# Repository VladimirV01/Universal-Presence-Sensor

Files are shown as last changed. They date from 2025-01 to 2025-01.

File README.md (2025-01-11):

# Universal Presence Sensor

This repository contains all the materials related to my **Universal Presence Sensor**, based on the **HLK-LD2410 radar sensor**.

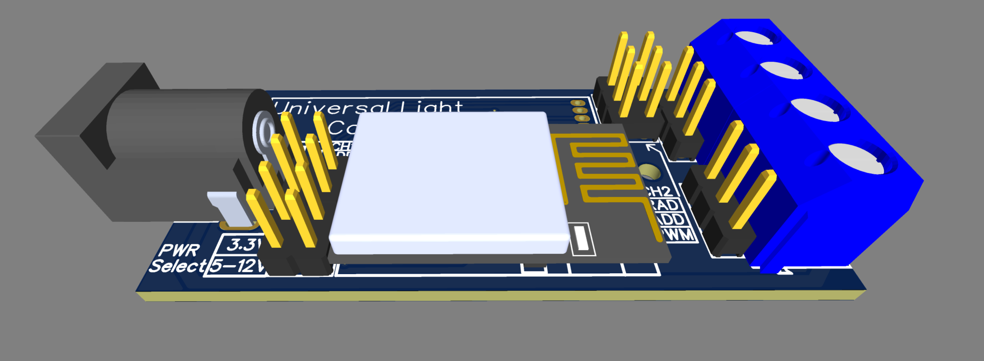
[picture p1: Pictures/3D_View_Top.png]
3D View of the Sensor
  
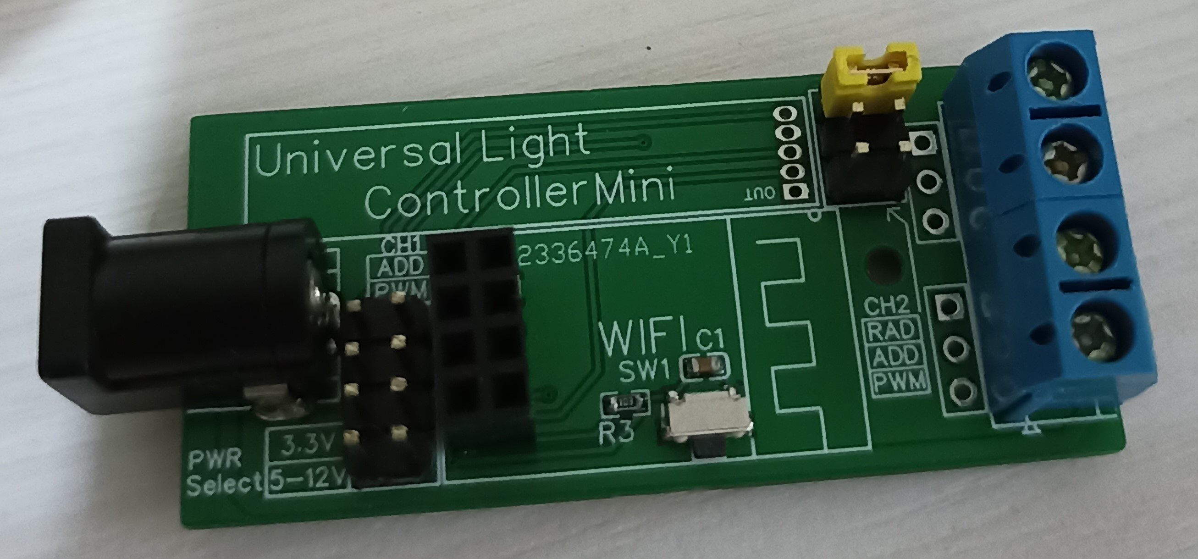
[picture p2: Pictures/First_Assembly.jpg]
Picture the Sensor
  

---

## **Features**
1. **ESP01 Module Powered by ESPHome**  
   The sensor runs ESPHome for seamless integration with Home Assistant.  

2. **Presence Detection with HLK-LD2410/HLK-LD2410B**  
   These affordable radar sensors ensure reliable presence detection.

3. **Power Supply**  
   - Standard **DC barrel jack** for power.  
   - Supports input voltage from **3.3V** up to **12V**.

4. **Configurable GPIOs**  
   The two available GPIOs can be configured to suit your specific needs.

5. **LED Strip Control**  
   - Supports brightness control for up to two 5V/12V standard LED strips via **PWM**.

6. **PIR Sensor Support**  
   Enhance presence detection with an additional **PIR motion sensor**.

---

## **Project Background**
This project began in **January 2023**, during the early days of my Home Assistant journey. At that time, presence sensors based on radar technology were expensive and hard to source in my country.  

While searching for an alternative, I discovered the **HLK-LD2410 sensors** on AliExpress at a very reasonable price. Excited by the opportunity, I purchased a few units and designed this sensor to integrate with Home Assistant using ESPHome.  

---

## **Configuration**
1. **Power**
	- Can be powered from 3.3V, in this case the "PWR Select" jumper should be set to 3.3V position
	- Can be powered from 5-12V, in which case the jumper should be changed, accordingly
	
2. **Channel 1**
	- Can control a strip of addressable LED (Set the "CH1" jumper to "ADD")
	- Can control a strip of simple LED via PWM (Set the "CH1" jumper "PWM")
	- Can be used as input (Set the "CH1" jumper to "ADD" and configure it as input)
	
3. **Channel 2**
	- Can be connected to the Radar output (Set the "CH2" jumper "RAD")
	- Can control a strip of addressable LED (Set the "CH2" jumper "ADD")
	- Can control a strip of simple LED via PWM (Set the "CH2" jumper "PWM")
	- Can be used as input (Set the "CH2" jumper to "ADD" and configure it as input)
	
### **Note:**
Please take into consideration that if you plan to control a LED strip, the input power you are giving to the module should match the power needed for the strip, as it is powered directly from the input.

Example 1: If you want to power a WS2812B strip of addressable LEDs, then you need to power the module from 5V and set the input power jumper accordingly.

Example 2: If you want to control a 12V simple Cold White LED strip, you need to power the module from 12V.

Example 3: If you want to use the module for presence detection only, paired with the radar sensor, it can be safely powered from 3.3V only.

---

## **Use Cases**
Currently, I have **three sensors** installed in my home, each serving unique purposes:

1. **Bathroom Automation**  
   - Installed to automate the lights.  
   - Operates with a success rate of **99.5%**, with no false positives and almost no false negatives.  

2. **Work Desk Setup**  
   - Equipped with one radar and one PWM output to control a LED strip that illuminates my keyboard based on specific conditions.  

3. **Closet Lighting**  
   - Similar to the bathroom sensor, it controls the lights.  
   - Performance is slightly affected by the closet’s layout, as items may obstruct the radar’s view in certain scenarios.  

---

## **Why This Project?**
At the time, affordable radar-based presence sensors were a rarity. By creating this sensor, I managed to fill a gap in the market while learning and experimenting with Home Assistant and ESPHome.  

---

## **Improvements for next version:**
- Power via Type C
- Decrease the footprint
- Revisit the case
- Make the case assembly snap in place without screws
- Add ferrite beads on the power line to the PIR sensor to try and solve the false positives

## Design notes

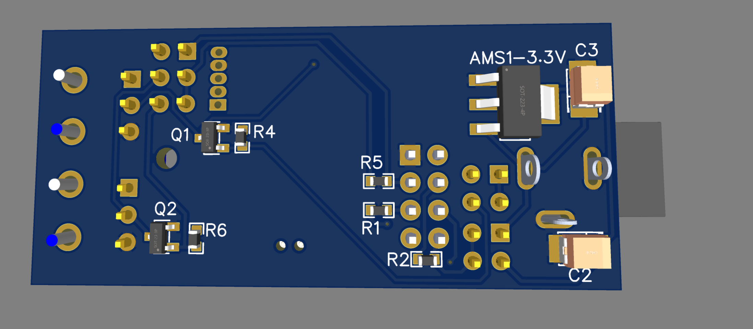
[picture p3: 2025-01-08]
Pictures/3D_View_Bottom.png

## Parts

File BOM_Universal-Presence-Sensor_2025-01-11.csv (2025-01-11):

ID | Name | Designator | Footprint | Quantity | Manufacturer Part | Comment
1 | AMS1117-3.3V | AMS1-3.3V | SOT-223-4_L6.5-W3.5-P2.30-LS7.0-BR | 1 | AMS1117-3.3V | Not needed if powered by 3.3V and the PWR jumper set accordingly.
2 | 0.1u | C1 | C0603 | 1 |  | Not mandatory but beneficial if Reset button is soldered
3 | 10uF Tantalum | C2,C3 | CAP-SMD_L3.5-W2.8 | 2 | TCQB686M006R0070E | Not needed if powered by 3.3V
4 | DC JACK | DC1 | DC-IN-TH_DC-005-20A | 1 | DC-005-20A | Input power socket
5 | LED1 | J1 | HDR-M-2.54_1X3 | 1 |  | Optional header for connecting Addressable LEDs
6 | Ch1 Select | J2 | HDR-M-2.54_2X2 | 1 |  | Jumper for selecting the CH1 fucntionality. Not mandatory, can be a solder bridge
7 | LED2 | J3 | HDR-M-2.54_1X3 | 1 |  | Optional header for connecting Addressable LEDs
8 | Bypass Reg | J5 | HDR-M-2.54_2X2 | 1 |  | Jumper to select the power option. Not mandatory, can be a solder bridge
9 | Ch2 select | J6 | HDR-M-2.54_2X3 | 1 |  | Jumper for selecting the CH2 fucntionality. Not mandatory, can be a solder bridge
10 | IRLML2502 | Q1,Q2 | SOT-23-3_L2.9-W1.3-P1.90-LS2.4-BR | 2 | IRLML2502 | MOSFETs used to drive the LED strips (not addressable) using the PWM from the ESP. Not needed if no LED strips will be used.
11 | 100 Ohm | R1,R5 | R0603 | 2 |  | Resistors for driving the mosfets. Not needed if no MOSFETs are soldered.
12 | 1K | R2 | R0603 | 1 |  | This is important to be soldered. Without it the ESP will not power on.
13 | 10k | R3 | R0603 | 1 |  | This is for the reset switch, can be omitted id the reset switch will not be soldered.
14 | 100k Ohm | R4,R6 | R0603 | 2 |  | Resistors for driving the mosfets. Not needed if no MOSFETs are soldered.
15 | RST | SW1 | KEY-SMD_K2-1806SA-AXXW-XX | 1 | K2-1806SA-A3DW-04 | Reset switch. Added it for convenience but never actually used it.
16 | LED1 | U1 | CONN-TH_2P-P5.00_DB301V-5.0-2P-BU-P | 1 | DB301V-5.0-2P-BU-P | Optional screw terminal for connecting 12V LED strips.
17 | ESP-01 | U2 | WIFIM-TH_8P-L24.7-W14.4-P2.54 | 1 | ESP-01 | The MCU
18 | LED2 | U3 | CONN-TH_2P-P5.00_DB301V-5.0-2P-BU-P | 1 | DB301V-5.0-2P-BU-P | Optional screw terminal for connecting 12V LED strips.
19 | HLK-LD2410-24G | U4 | TH_HLK-LD2410-24G | 1 | HLK-LD2410-24G | The radar sensor.

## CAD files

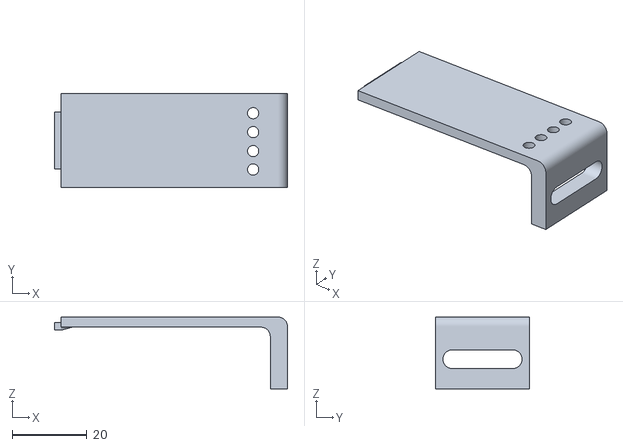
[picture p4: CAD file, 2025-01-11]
3D Files/TOP With Output.stl
62.2 x 25.2 x 19.2

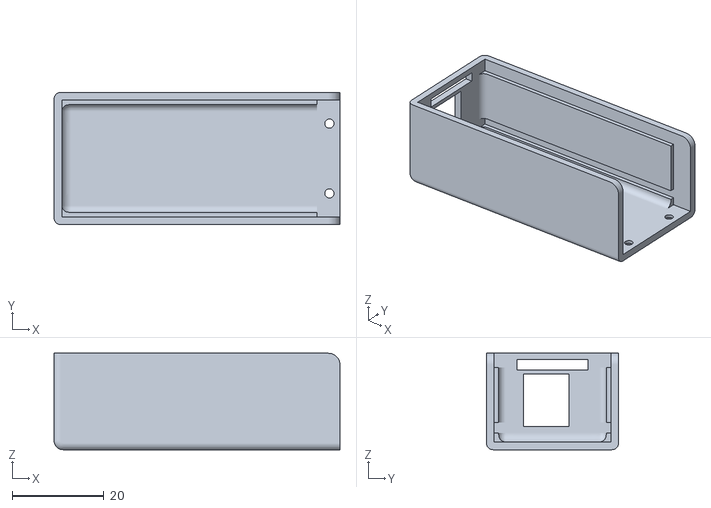
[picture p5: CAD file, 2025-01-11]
3D Files/Bottom.stl
62.2 x 28.8 x 21.0

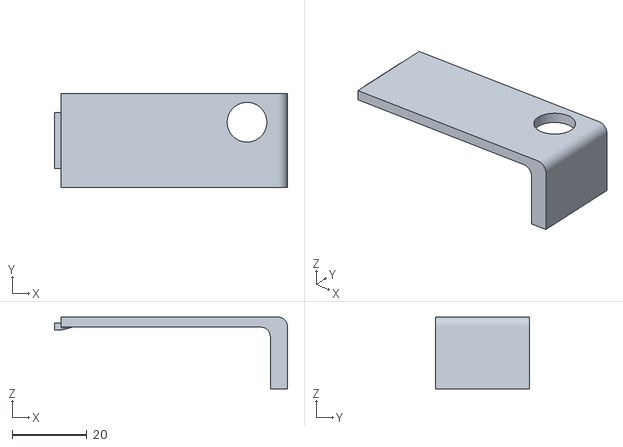
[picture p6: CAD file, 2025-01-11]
3D Files/TOP Pir.stl
62.2 x 25.2 x 19.2

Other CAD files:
3D Files/TOP Clean.stl

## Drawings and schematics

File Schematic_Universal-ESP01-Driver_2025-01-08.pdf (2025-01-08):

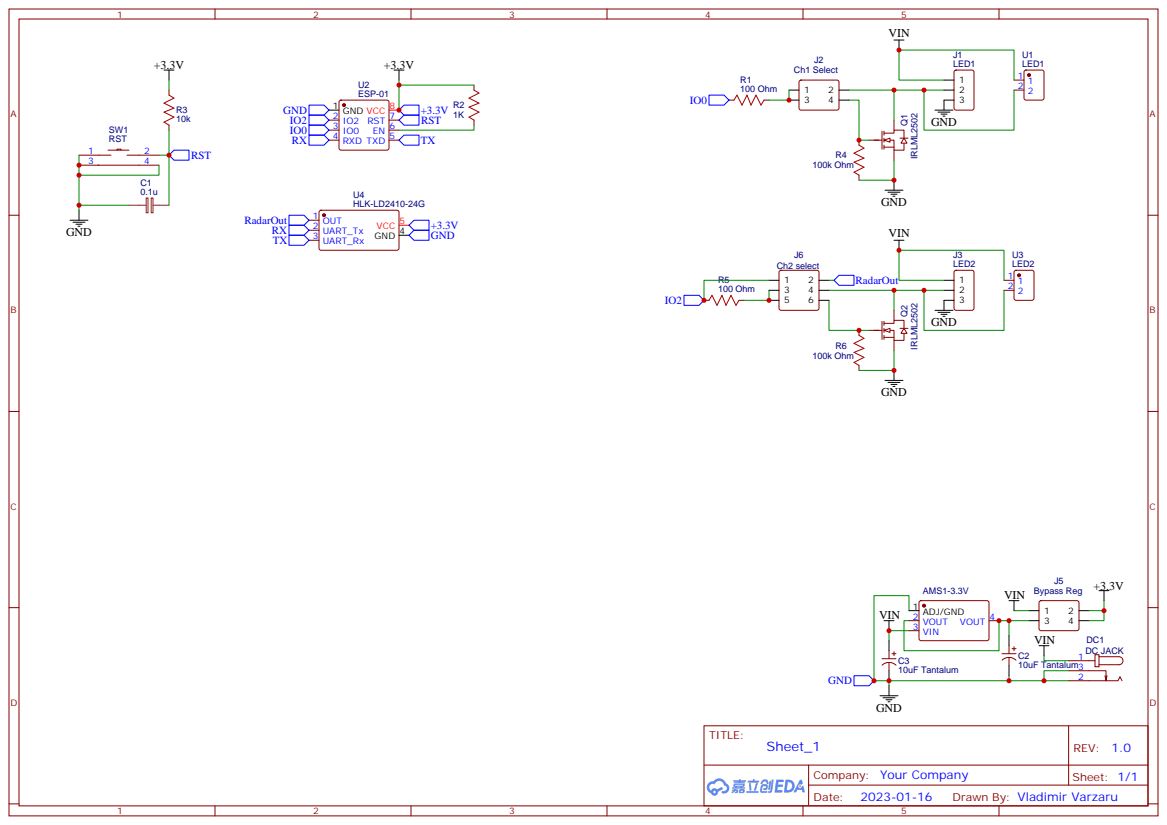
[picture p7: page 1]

Drawn By: Vladimir Varzaru

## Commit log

2025-01-08 Added picture of the sensor when first assembled by me.
2025-01-11 Added the BOM with corresponding comments.
    [BOM_Universal-Presence-Sensor_2025-01-11.csv]
2025-01-11 Added the 3D files for the case
    [Bottom.stl, TOP Clean.stl, TOP Pir.stl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]
